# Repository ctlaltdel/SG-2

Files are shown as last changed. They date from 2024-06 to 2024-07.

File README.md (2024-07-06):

# SG-2 Synthesiser Guitar

## An experimental synth intended to be playable like a guitar

- 2 voices
- A softpot per voice for pitch selection
- A guitar string amplitude detector per voice for volume envelope
- Cartridge port for synth parameter selection

The synth is based around a Daisy Seed from Electrosmith, mounted in a custom PCB that provides the current sources and gating for the softpots, the string amplitude detectors for the voice envelopes, and the cartridge port interface. Power is provided via an internal USB powerbank, charged via a port mounted on the pickguard.

Current status: 
- Revision B of the main electronics board testing complete, awaiting permanent installation
- Port of Op6daisy FM synth engine by @carlvp up and running, including loading synth voice program from cartridge! 

Still to do:
- Add touch-sensitive pads to allow scale shifting up/down to mitigate the limitation of having only 2 strings
- Add a touch control to toggle \'stringless\' playing of the pitch softpots

Here\'s a video that hopefully gives some idea of what I'm aiming at: 

https://www.youtube.com/watch?v=BWaMOtsjMRc

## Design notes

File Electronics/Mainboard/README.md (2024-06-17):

### Credits

- The idea to use constant current to drive the softpots (which allows two-finger hammer-ons and pull-offs) instead of voltage  came from this article:

https://paia.com/dual-ribbon-howto/

- I was having trouble with sound artifacts on finger-off, which was solved with gating based heavily on user frijitz\'s posts on this thread:

https://electro-music.com/forum/topic-32246.html

- The preamp and peak detector of string envelope demodulation stages are based on the Sound Detector product from Sparkfun: 

https://www.sparkfun.com/products/12642

Original schematic by Bryan Jacquot may be found at:

https://cdn.sparkfun.com/assets/8/a/1/2/5/sound-detector-v11.pdf

Note the schematic for this product is released under the Creative Commons
Attribution Share-Alike 3.0 License: https://creativecommons.org/licenses/by-sa/3.0/

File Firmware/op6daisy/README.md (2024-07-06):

This is an adaption of the op6daisy firmware by carlvp: https://github.com/carlvp/daisylab/tree/main/op6daisy

The following modifications have been made:

* There is a single channel with 2 voices, 1 per pitch softpot
* The firmware is limited to a single voice program
* The MIDI dispatcher has been replaced by a routine that monitors the pitch gate signals and string envelope amplitudes
* The synth voice program is loaded from a cartridge (EEPROM connected via I2C), which is hot-swappable

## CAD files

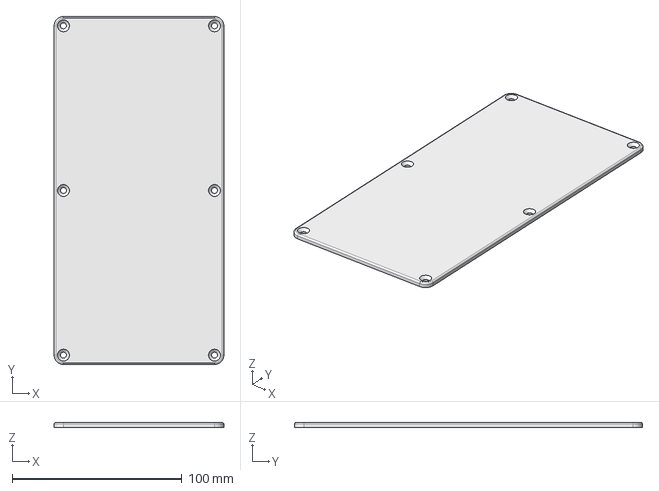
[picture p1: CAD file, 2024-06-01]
Mechanical/Backplate/backplate.FCStd
100.0 x 205.0 x 3.00 mm

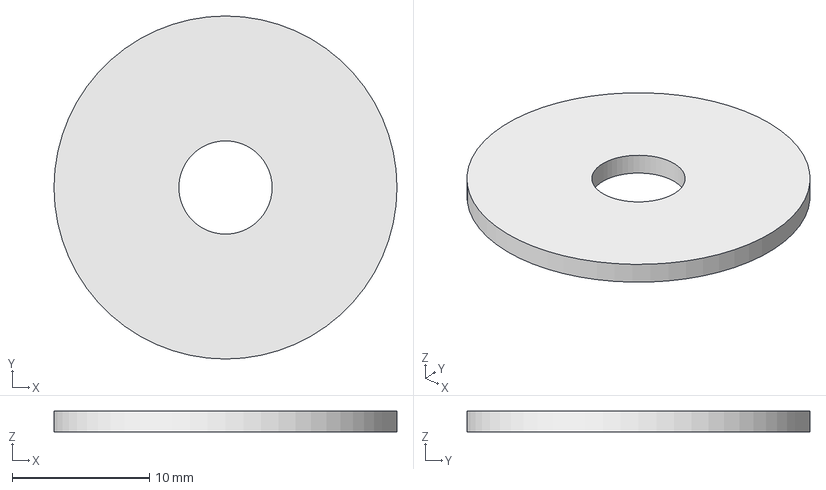
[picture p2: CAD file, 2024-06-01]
Mechanical/Misc/volume knob mount.FCStd
25.0 x 25.0 x 1.50 mm

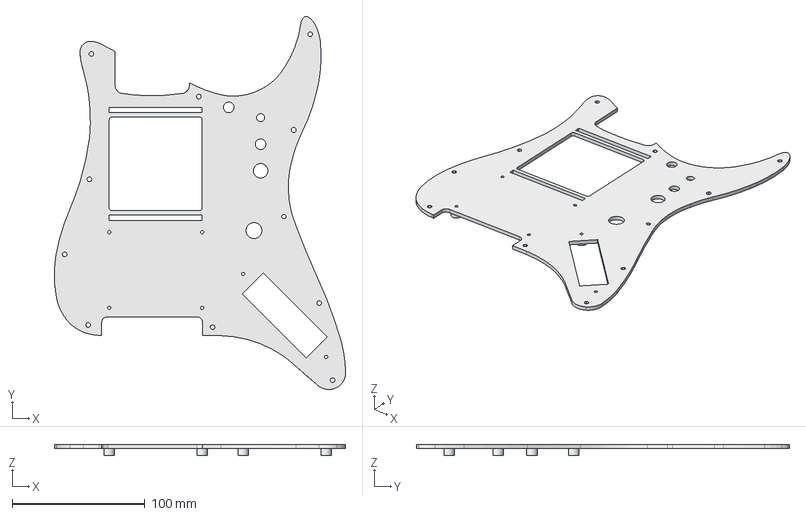
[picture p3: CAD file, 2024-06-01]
Mechanical/Pickguard/Pickguard.FCStd
219.3 x 280.9 x 8.00 mm

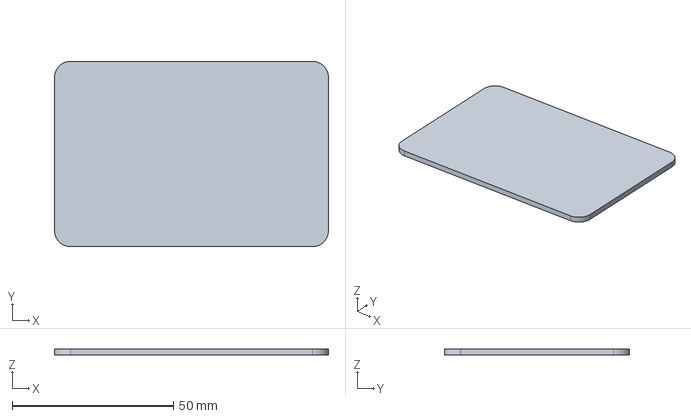
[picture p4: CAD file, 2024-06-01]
Mechanical/Misc/wiring cover.FCStd
85.0 x 57.5 x 2.00 mm

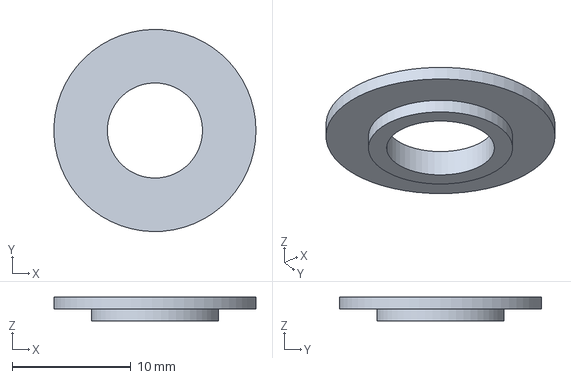
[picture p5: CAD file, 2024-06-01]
Mechanical/Misc/charging socket mount.FCStd
17.0 x 17.0 x 2.00 mm

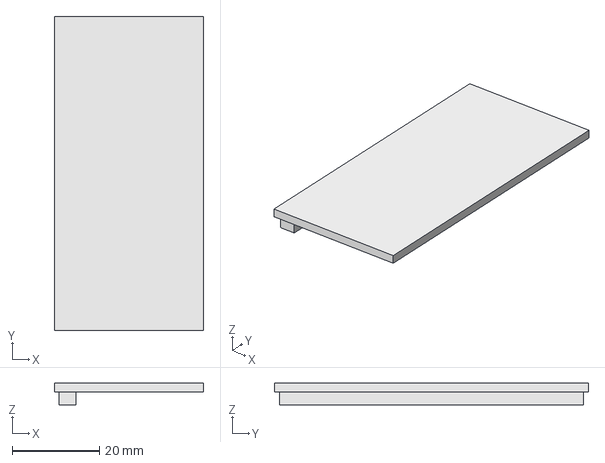
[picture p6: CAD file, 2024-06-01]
Mechanical/Misc/blanking plate.FCStd
34.2 x 72.0 x 5.00 mm

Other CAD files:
Mechanical/Backplate/backplate.stl
Mechanical/Pickguard/Pickguard.stl

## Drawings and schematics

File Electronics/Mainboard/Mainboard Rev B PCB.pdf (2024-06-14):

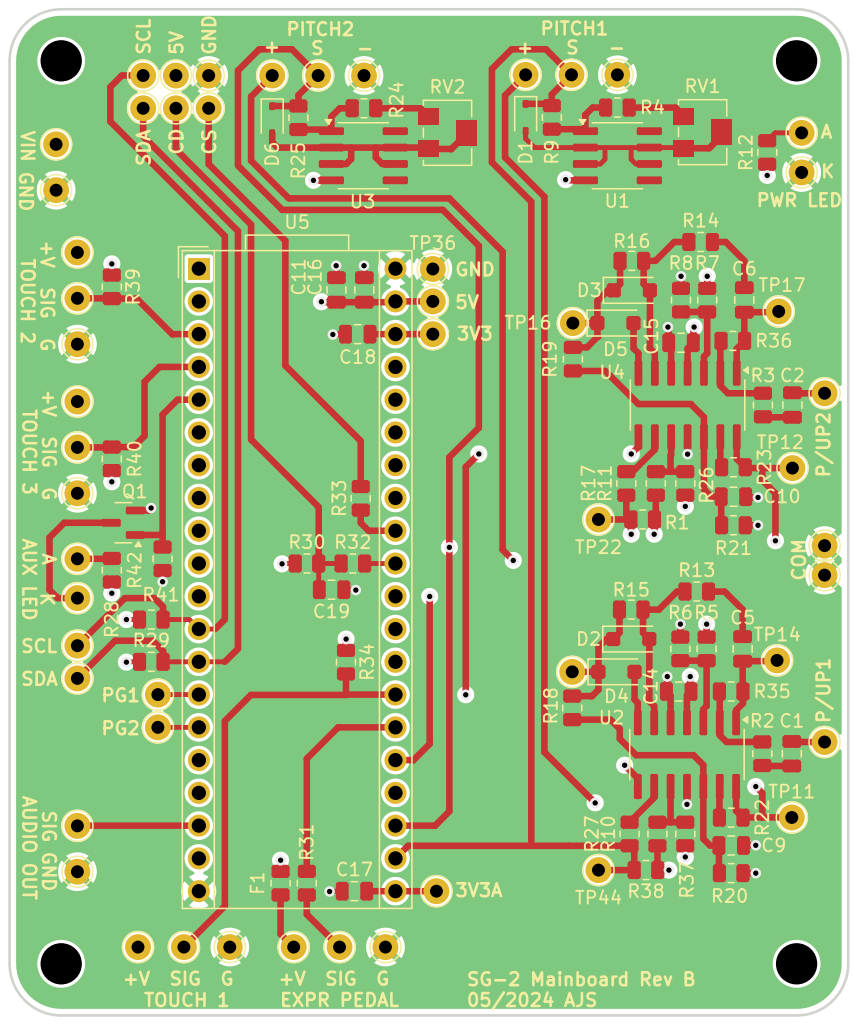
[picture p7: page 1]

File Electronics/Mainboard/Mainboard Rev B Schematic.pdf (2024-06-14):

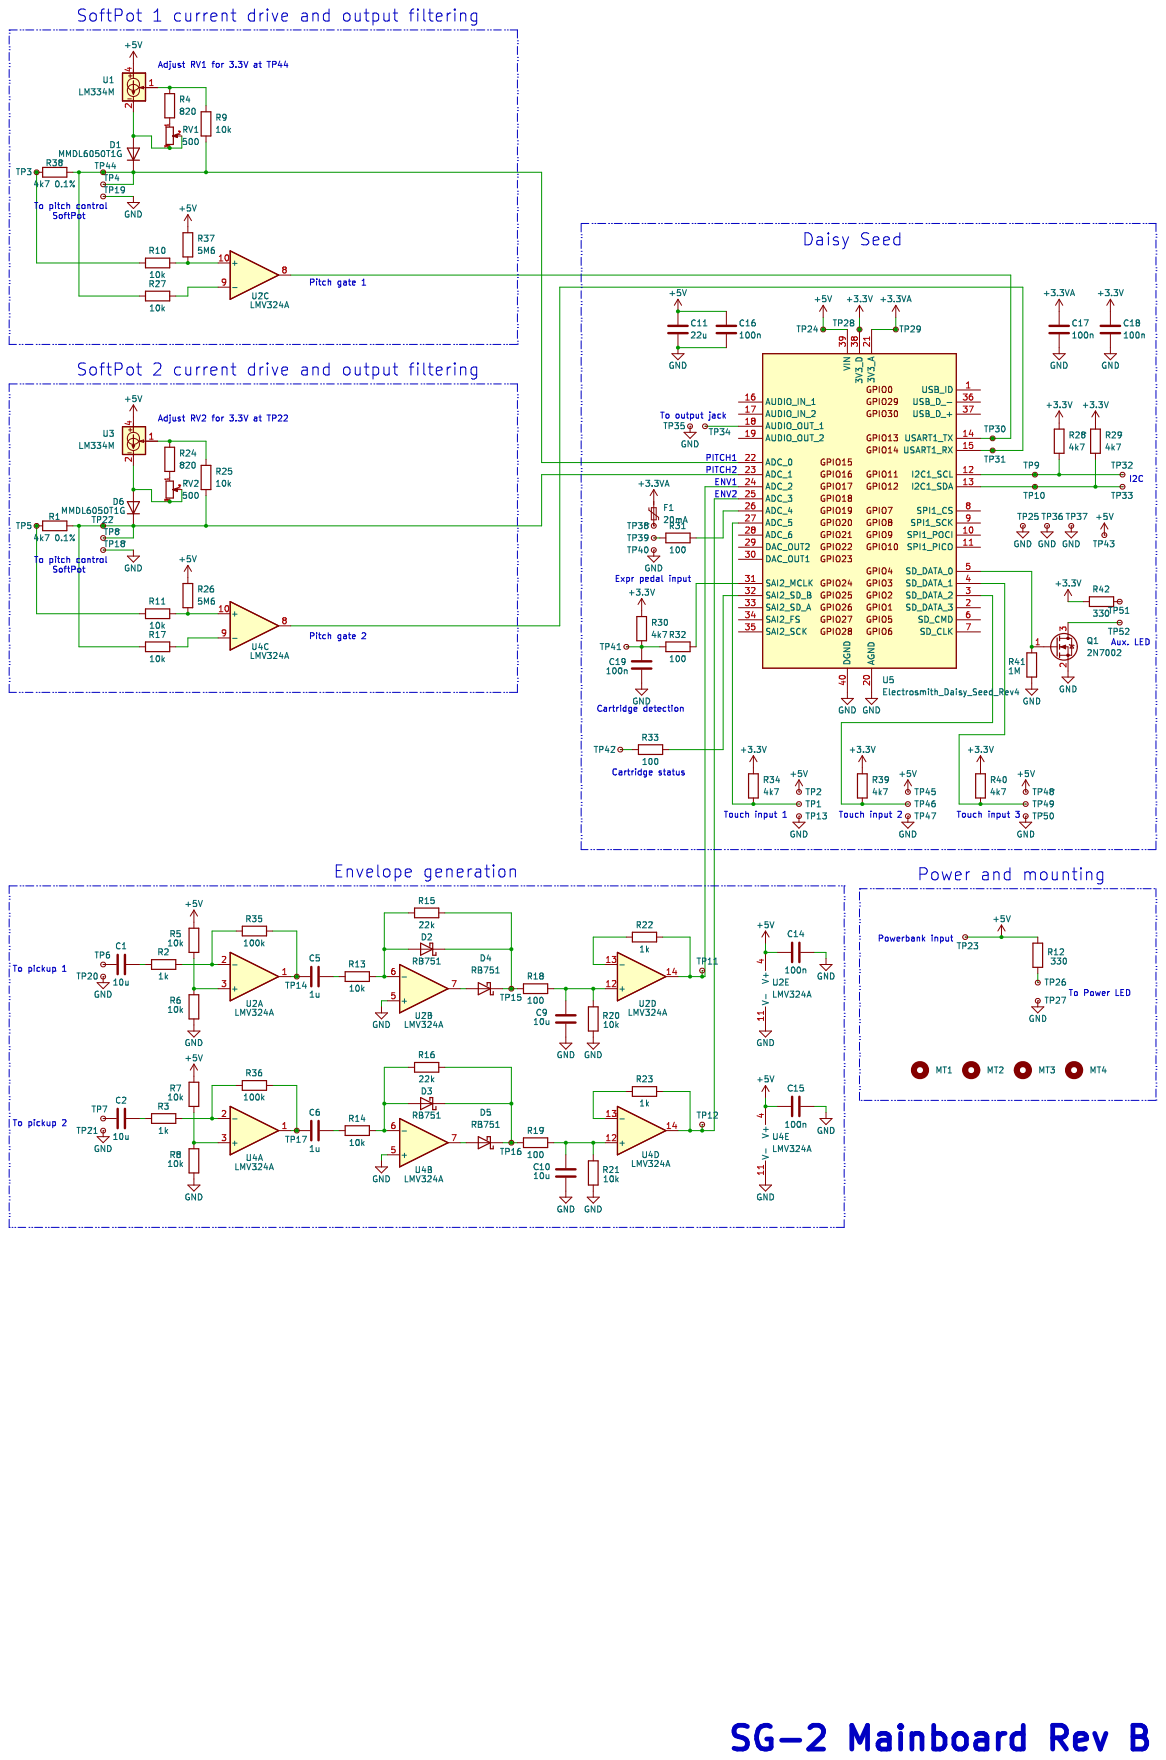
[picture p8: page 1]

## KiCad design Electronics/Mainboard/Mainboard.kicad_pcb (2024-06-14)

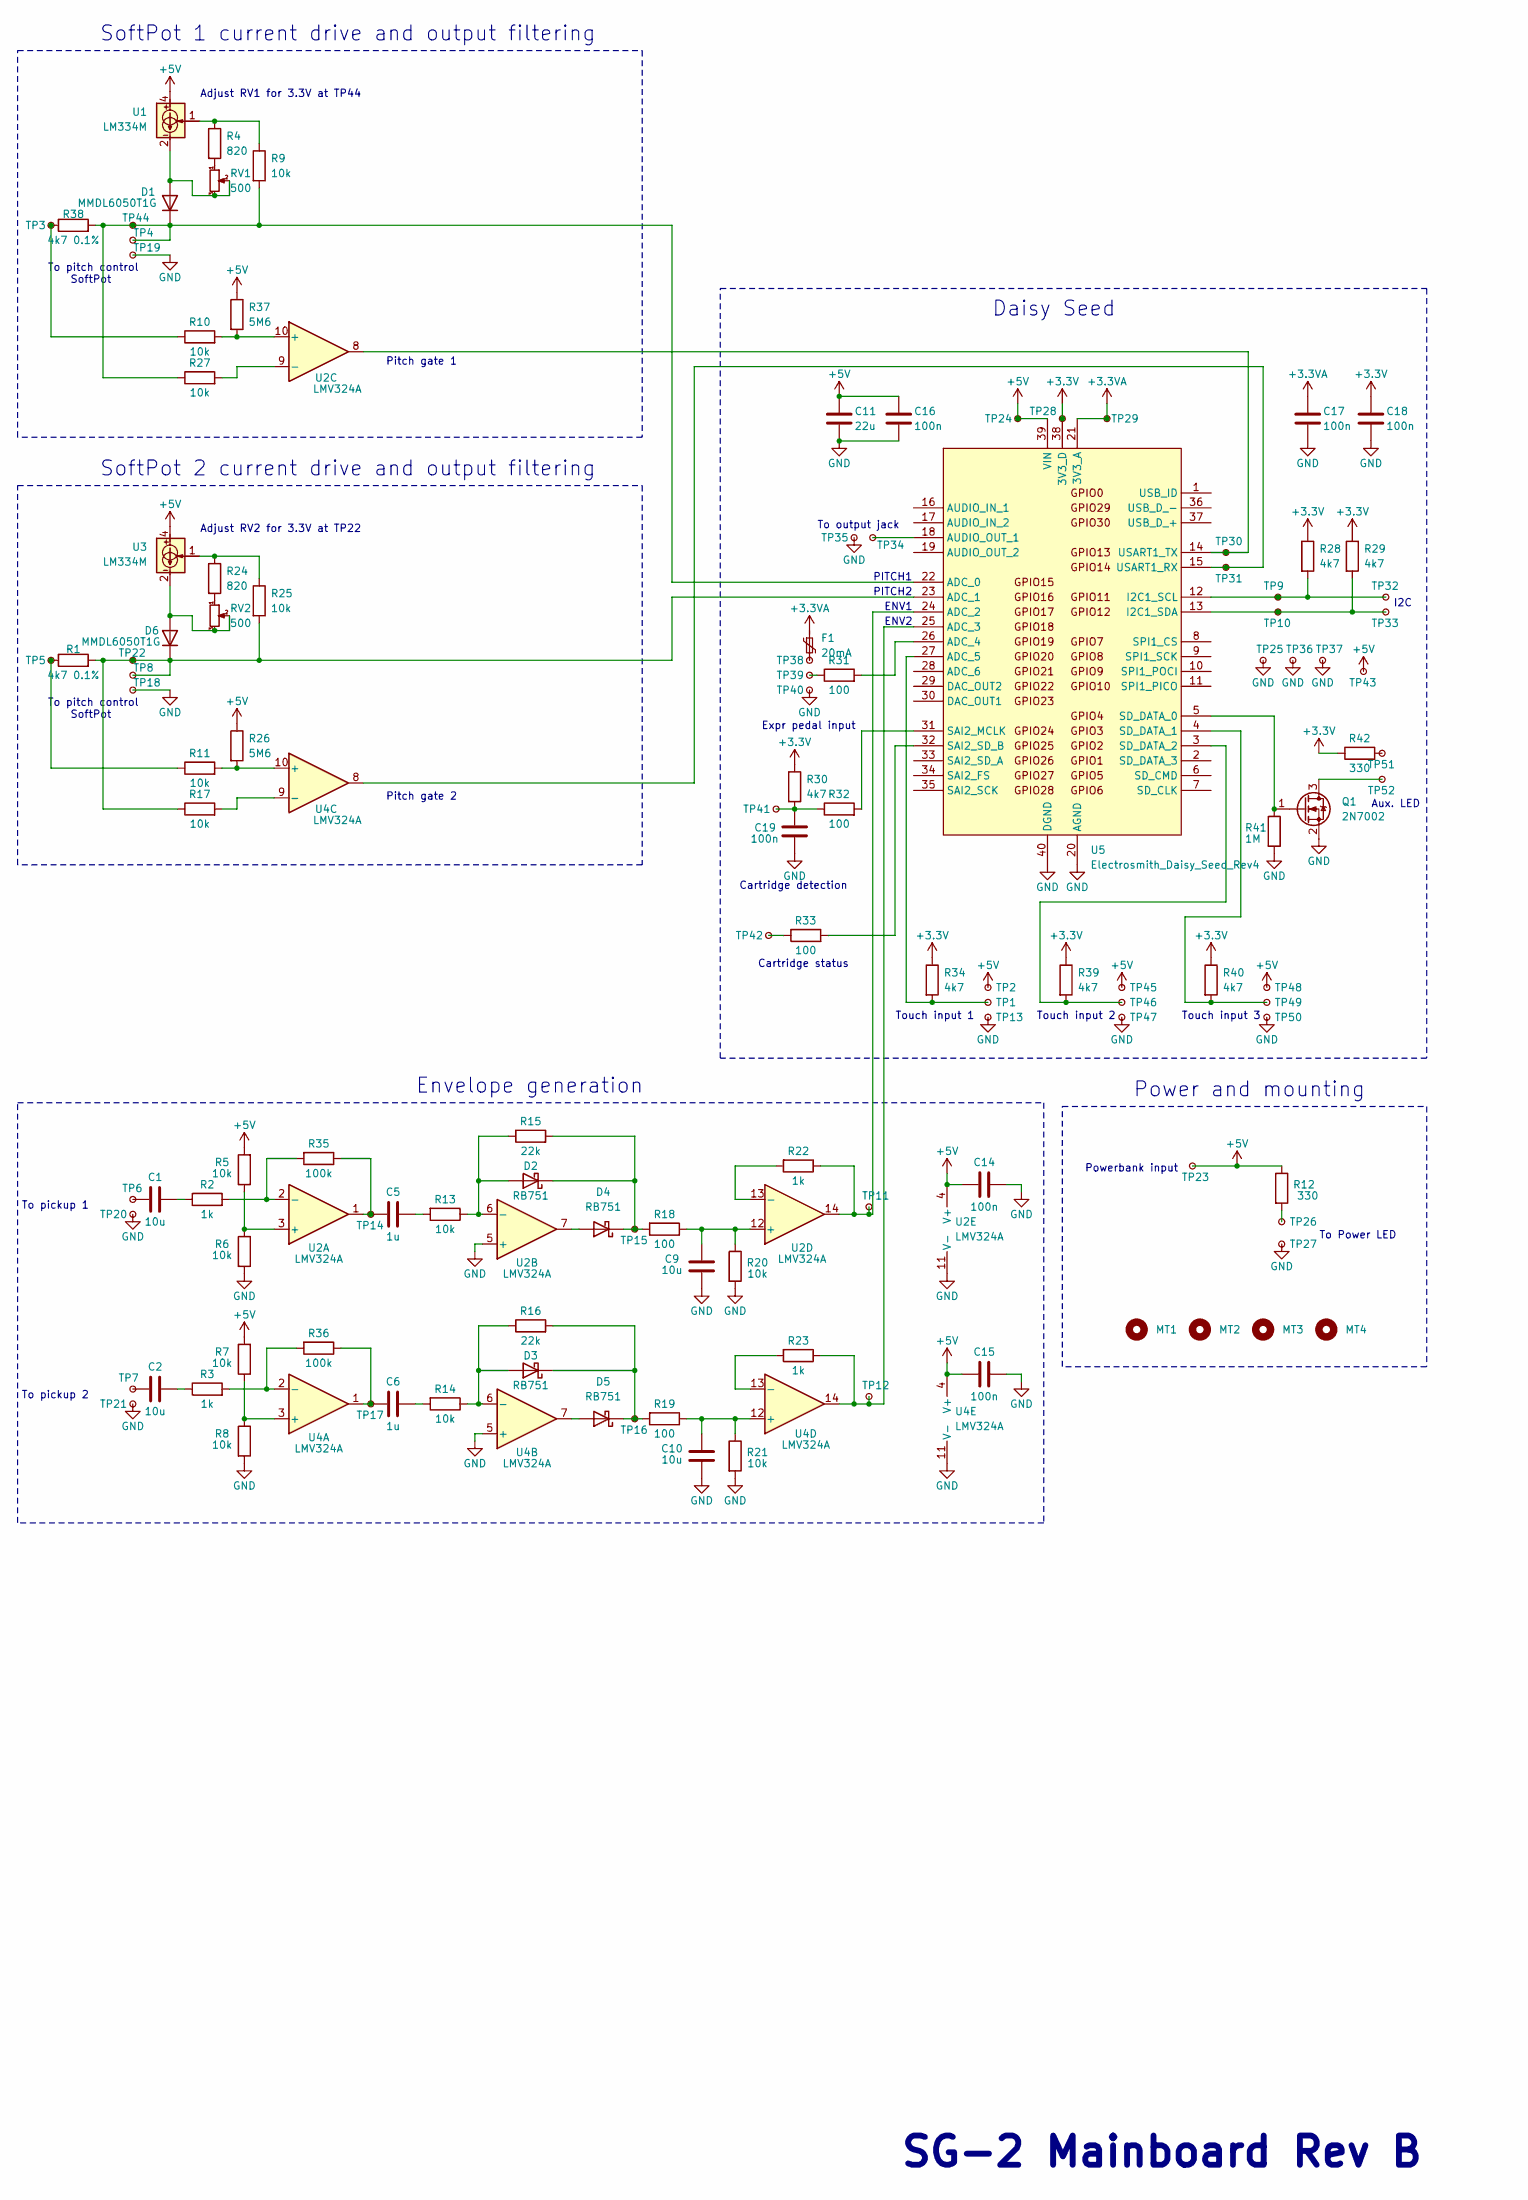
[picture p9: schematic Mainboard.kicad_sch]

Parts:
C1, C2, C9, C10: 10u; C_0805_2012Metric
C5, C6: 1u; C_0805_2012Metric
C11: 22u; C_0805_2012Metric
C14, C15, C16, C17, C18, C19: 100n; C_0805_2012Metric
D1, D6: MMDL6050T1G; D_SOD-323
D2, D3, D4, D5: RB751; D_SOD-123F
F1: 20mA; R_0805_2012Metric
MT1, MT2, MT3, MT4: MountingHole; MountingHole_3.2mm_M3
Q1: 2N7002; SOT-23
R1, R38: 4k7 0.1%; R_0805_2012Metric
R2, R3, R22, R23: 1k; R_0805_2012Metric
R4, R24: 820; R_0805_2012Metric
R5, R6, R7, R8, R9, R10, R11, R13, R14, R17, R20, R21, R25, R27: 10k; R_0805_2012Metric
R12, R42: 330; R_0805_2012Metric
R15, R16: 22k; R_0805_2012Metric
R18, R19, R31, R32, R33: 100; R_0805_2012Metric
R26, R37: 5M6; R_0805_2012Metric
R28, R29, R30, R34, R39, R40: 4k7; R_0805_2012Metric
R35, R36: 100k; R_0805_2012Metric
R41: 1M; R_0805_2012Metric
RV1, RV2: 500; Potentiometer_Bourns_3224W_Vertical
TP1, TP2, TP3, TP4, TP5, TP6, TP7, TP8, TP9, TP10, TP11, TP12, TP13, TP14, TP15, TP16, TP17, TP18, TP19, TP20, TP21, TP22, TP23, TP24, TP25, TP26, TP27, TP28, TP29, TP30, TP31, TP32, TP33, TP34, TP35, TP36, TP37, TP38, TP39, TP40, TP41, TP42, TP43, TP44, TP45, TP46, TP47, TP48, TP49, TP50, TP51, TP52: TestPoint_Small; TestPoint_THTPad_D2.0mm_Drill1.0mm
U1, U3: LM334M; SOIC-8_3.9x4.9mm_P1.27mm
U2, U4: LMV324A; SOIC-14_3.9x8.7mm_P1.27mm
U5: Electrosmith_Daisy_Seed_Rev4; Electrosmith_Daisy_Seed

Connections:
+3.3V: C18.2, R28.1, R29.1, R30.1, R34.1, R39.1, R40.1, R42.1, TP28.1, U5.38 (3V3_D)
+3.3VA: C17.2, F1.1, TP29.1, U5.21 (3V3_A)
+5V: C11.2, C14.2, C15.2, C16.2, R5.2, R7.2, R12.1, R26.1, R37.1, TP2.1, TP23.1, TP24.1, TP43.1, TP45.1, TP48.1, U1.4, U2.4 (V+), U3.4, U4.4 (V+), U5.39 (VIN)
GND: C9.2, C10.2, C11.1, C14.1, C15.1, C16.1, C17.1, C18.1, C19.1, Q1.2 (S), R6.2, R8.2, R20.2, R21.2, R41.2, TP13.1, TP18.1, TP19.1, TP20.1, TP21.1, TP25.1, TP27.1, TP35.1, TP36.1, TP37.1, TP40.1, TP47.1, TP50.1, U2.5 (+), U2.11 (V-), U4.5 (+), U4.11 (V-), U5.20 (AGND), U5.40 (DGND)
unnamed: C1.1, R2.1
unnamed: C1.2, TP6.1
unnamed: C2.1, R3.1
unnamed: C2.2, TP7.1
unnamed: C5.1, R13.2
unnamed: C5.2, R35.1, TP14.1, U2.1
unnamed: C6.1, R14.2
unnamed: C6.2, R36.1, TP17.1, U4.1
unnamed: C19.2, R30.2, R32.1, TP41.1
unnamed: D1.2 (A), RV1.2, RV1.3, U1.2, U1.3, U1.6, U1.7
unnamed: D1.1 (K), R9.2, R27.1, R38.2, TP4.1, TP44.1, U5.22 (ADC_0)
unnamed: D2.2 (A), R13.1, R15.1, U2.6 (-)
unnamed: D2.1 (K), D4.1 (K), R15.2, R18.2, TP15.1
unnamed: D3.2 (A), R14.1, R16.1, U4.6 (-)
unnamed: D3.1 (K), D5.1 (K), R16.2, R19.2, TP16.1
unnamed: D4.2 (A), U2.7
unnamed: D5.2 (A), U4.7
unnamed: D6.2 (A), RV2.2, RV2.3, U3.2, U3.3, U3.6, U3.7
unnamed: D6.1 (K), R1.2, R17.1, R25.2, TP8.1, TP22.1, U5.23 (ADC_1)
unnamed: F1.2, TP38.1
unnamed: Q1.3 (D), TP52.1
unnamed: Q1.1 (G), R41.1, U5.5 (SD_DATA_0)
unnamed: R1.1, R11.1, TP5.1
unnamed: R4.1, R9.1, U1.1
unnamed: R4.2, RV1.1
unnamed: R10.1, R38.1, TP3.1
unnamed: R12.2, TP26.1
unnamed: R24.1, R25.1, U3.1
unnamed: R24.2, RV2.1
unnamed: R31.1, TP39.1
unnamed: R33.1, TP42.1
unnamed: R42.2, TP51.1
unnamed: R5.1, R6.1, U2.3 (+)
unnamed: R2.2, R35.2, U2.2 (-)
unnamed: R10.2, R37.2, U2.10 (+)
unnamed: R27.2, U2.9 (-)
unnamed: C9.1, R18.1, R20.1, U2.12 (+)
unnamed: R22.2, U2.13 (-)
unnamed: R7.1, R8.1, U4.3 (+)
unnamed: R3.2, R36.2, U4.2 (-)
unnamed: R11.2, R26.2, U4.10 (+)
unnamed: R17.2, U4.9 (-)
unnamed: C10.1, R19.1, R21.1, U4.12 (+)
unnamed: R23.2, U4.13 (-)
unnamed: R22.1, TP11.1, U2.14, U5.24 (ADC_2)
unnamed: R23.1, TP12.1, U4.14, U5.25 (ADC_3)
unnamed: R31.2, U5.26 (ADC_4)
unnamed: R34.2, TP1.1, U5.27 (ADC_5)
unnamed: TP34.1, U5.18 (AUDIO_OUT_1)
unnamed: R28.2, TP9.1, TP32.1, U5.12 (I2C1_SCL)
unnamed: R29.2, TP10.1, TP33.1, U5.13 (I2C1_SDA)
unnamed: R32.2, U5.31 (SAI2_MCLK)
unnamed: R33.2, U5.32 (SAI2_SD_B)
unnamed: R40.2, TP49.1, U5.4 (SD_DATA_1)
unnamed: R39.2, TP46.1, U5.3 (SD_DATA_2)
unnamed: TP31.1, U4.8, U5.15 (USART1_RX)
unnamed: TP30.1, U2.8, U5.14 (USART1_TX)

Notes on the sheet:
To Power LED
To output jack
Power and mounting
Cartridge status
Powerbank input
Cartridge detection
Pitch gate 1
Envelope generation
SoftPot 2 current drive and output filtering
Touch input 1
ENV2
Aux. LED
Adjust RV1 for 3.3V at TP44
To pitch control SoftPot
I2C
SoftPot 1 current drive and output filtering
Pitch gate 2
PITCH1
Touch input 2
Expr pedal input
To pickup 2
Daisy Seed
To pickup 1
PITCH2
SG-2 Mainboard Rev B
Adjust RV2 for 3.3V at TP22
Touch input 3
ENV1

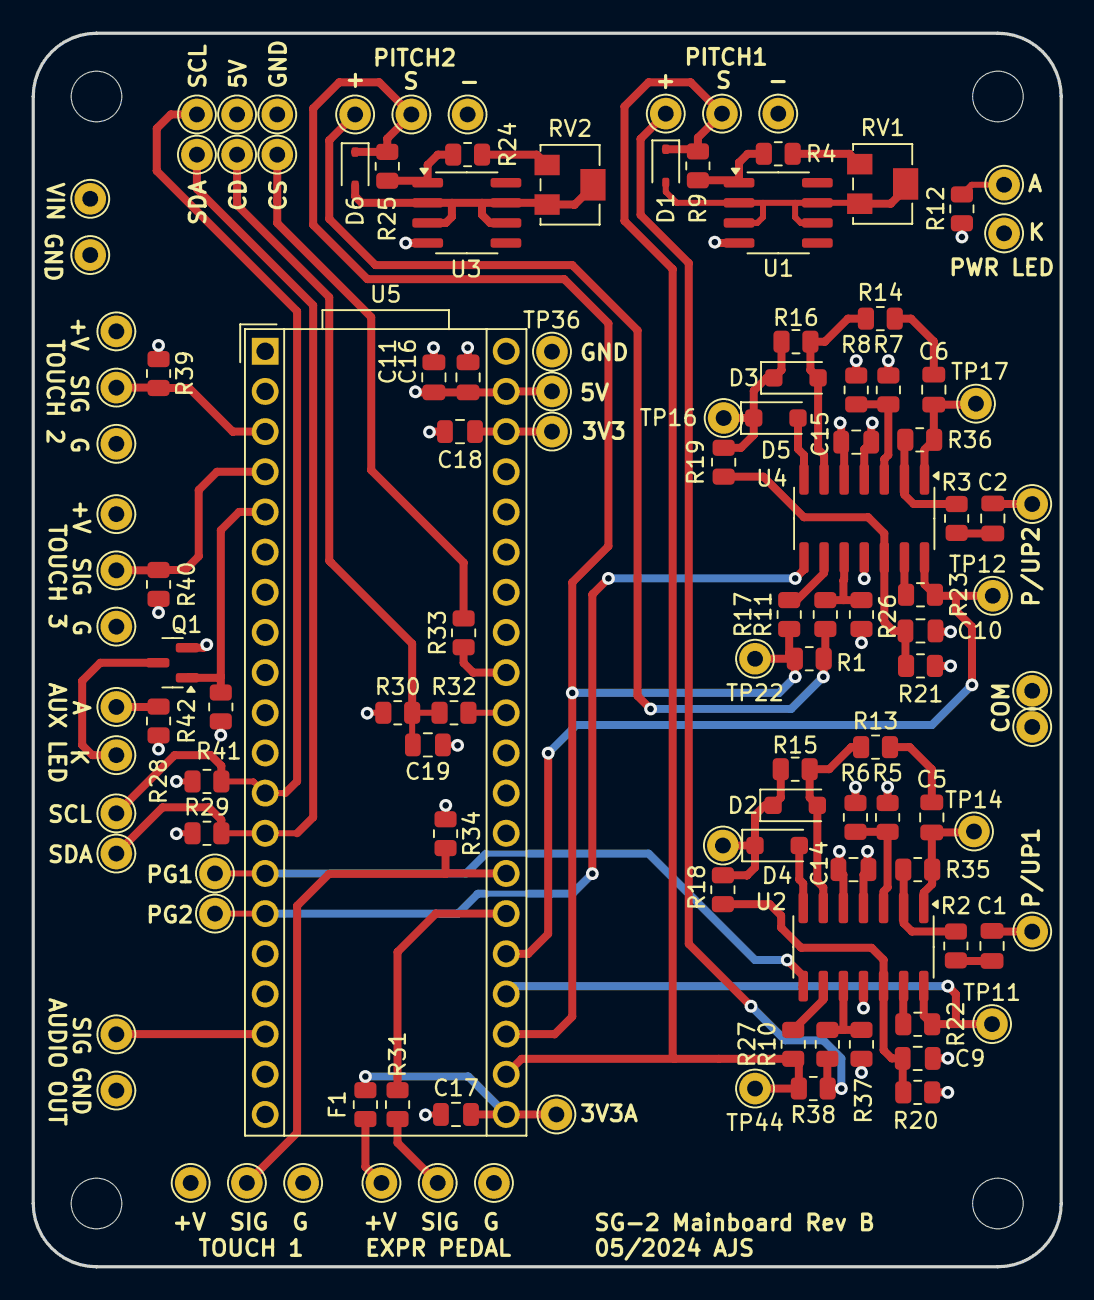
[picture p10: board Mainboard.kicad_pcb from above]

Board: 4 copper layers, 65.0 x 78.0 mm, 126 parts (0 on the bottom side), 61 nets.

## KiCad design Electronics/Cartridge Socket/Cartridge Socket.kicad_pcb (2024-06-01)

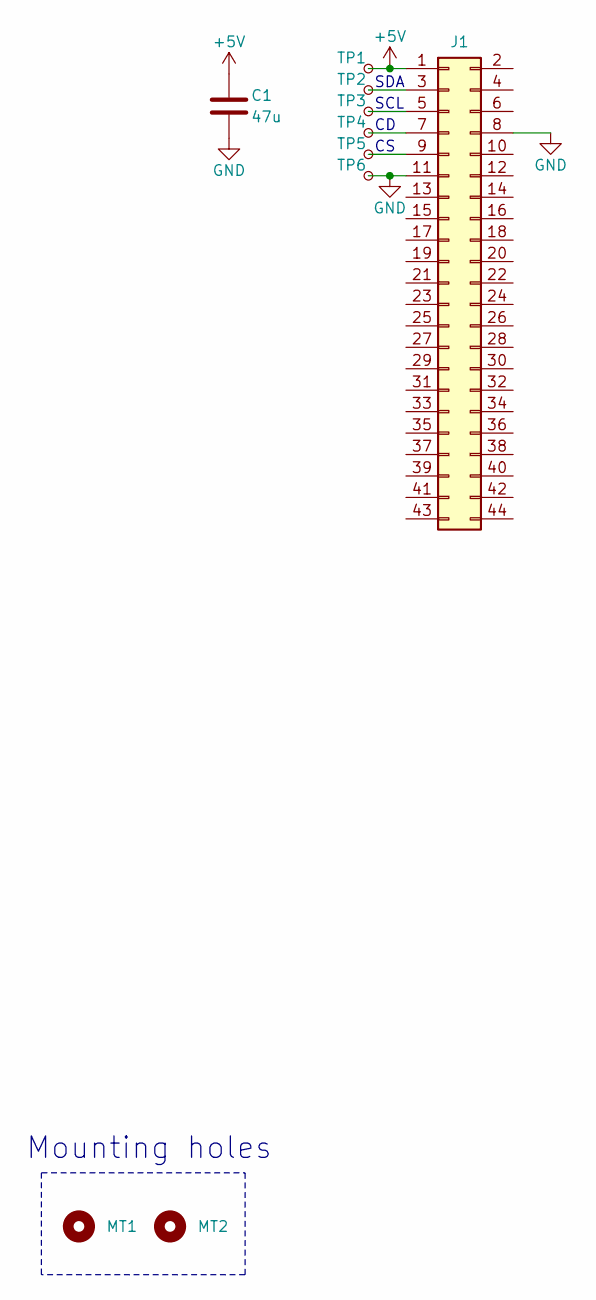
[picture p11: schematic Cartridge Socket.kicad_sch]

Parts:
C1: 47u; C_0805_2012Metric
J1: Conn_02x22_Odd_Even; TE_5530843-4
MT1, MT2: MountingHole; MountingHole_3.2mm_M3
TP1, TP2, TP3, TP4, TP5, TP6: TestPoint_Small; TestPoint_THTPad_D1.5mm_Drill0.7mm

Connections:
+5V: C1.2, J1.1, TP1.1
GND: C1.1, J1.8, J1.11, TP6.1
unnamed: J1.3, TP2.1
unnamed: J1.5, TP3.1
unnamed: J1.7, TP4.1
unnamed: J1.9, TP5.1

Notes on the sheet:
SCL
Mounting holes
SDA

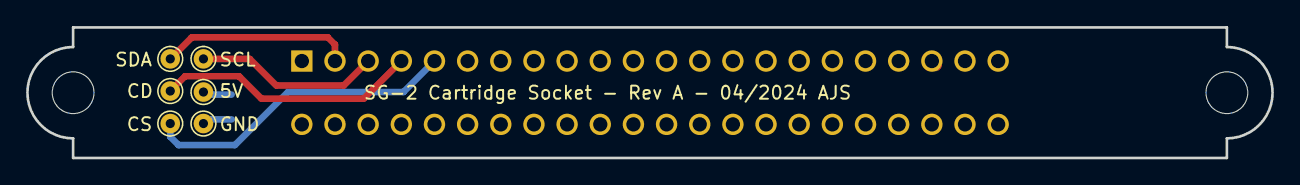
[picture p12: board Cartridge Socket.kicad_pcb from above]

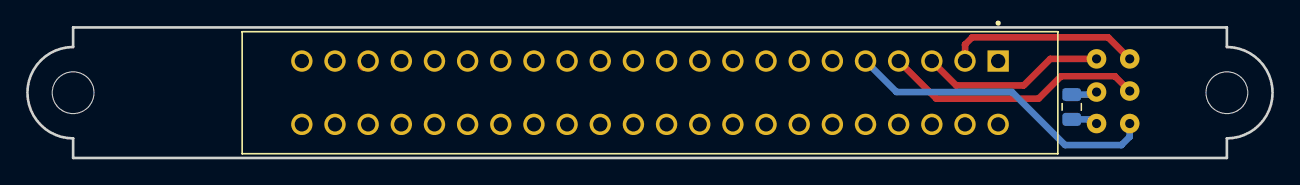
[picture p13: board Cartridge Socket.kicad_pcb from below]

Board: 4 copper layers, 95.4 x 10.0 mm, 10 parts (2 on the bottom side), 6 nets.

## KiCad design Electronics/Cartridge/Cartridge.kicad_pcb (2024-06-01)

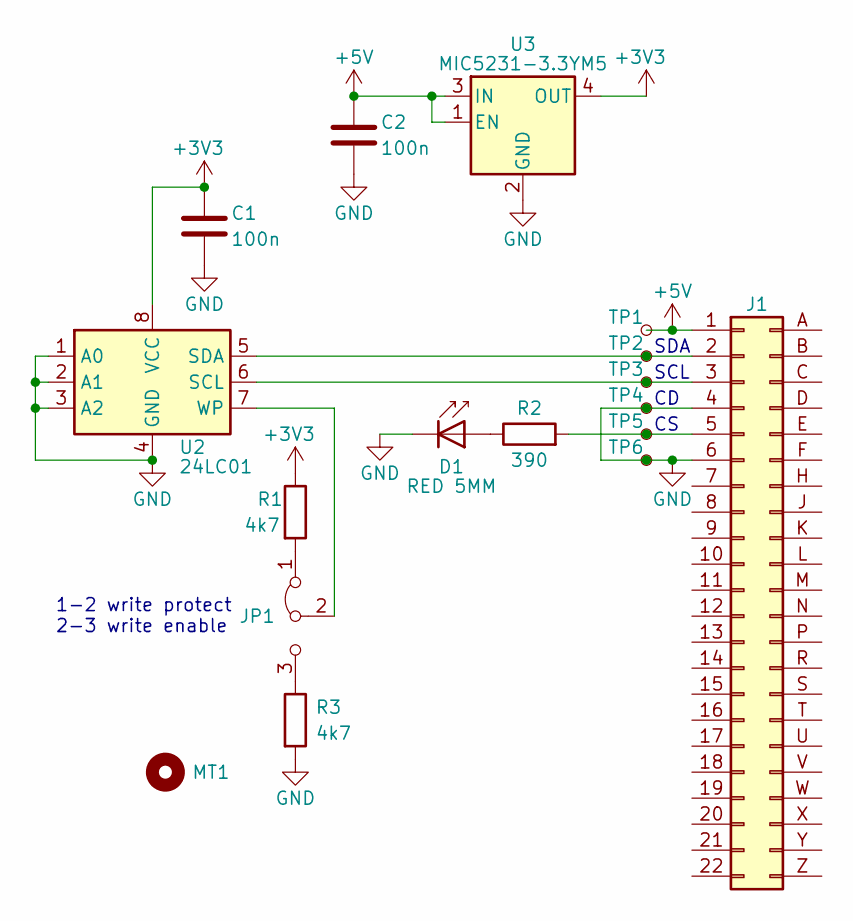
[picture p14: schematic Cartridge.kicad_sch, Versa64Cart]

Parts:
C1, C2: 100n; C_0603_1608Metric
D1: RED 5MM; LED_D5.0mm_IRGrey
J1: Conn_02x22_Odd_Even; C64_EXPANSION_PORT
JP1: Jumper_3_Bridged12; PinHeader_1x03_P2.54mm_Horizontal
MT1: MountingHole; MountingHole_5mm
R1, R3: 4k7; R_0805_2012Metric
R2: 390; R_0805_2012Metric
TP1, TP2, TP3, TP4, TP5, TP6: TestPoint_Small; TestPoint_THTPad_D1.5mm_Drill0.7mm
U2: 24LC01; SOIC-8_3.9x4.9mm_P1.27mm
U3: MIC5231-3.3YM5; SOT-23-5

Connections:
+3V3: C1.2, R1.1, U2.8 (VCC), U3.4 (OUT)
+5V: C2.2, J1.1, TP1.1, U3.1 (EN), U3.3 (IN)
GND: C1.1, C2.1, D1.1 (K), J1.4, J1.6, R3.2, TP4.1, TP6.1, U2.1 (A0), U2.2 (A1), U2.3 (A2), U2.4 (GND), U3.2 (GND)
unnamed: D1.2 (A), R2.1
unnamed: J1.5, R2.2, TP5.1
unnamed: JP1.1 (A), R1.2
unnamed: JP1.3 (B), R3.1
unnamed: JP1.2 (C), U2.7 (WP)
unnamed: J1.3, TP3.1, U2.6 (SCL)
unnamed: J1.2, TP2.1, U2.5 (SDA)

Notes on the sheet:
SDA
SCL
1-2 write protect 2-3 write enable

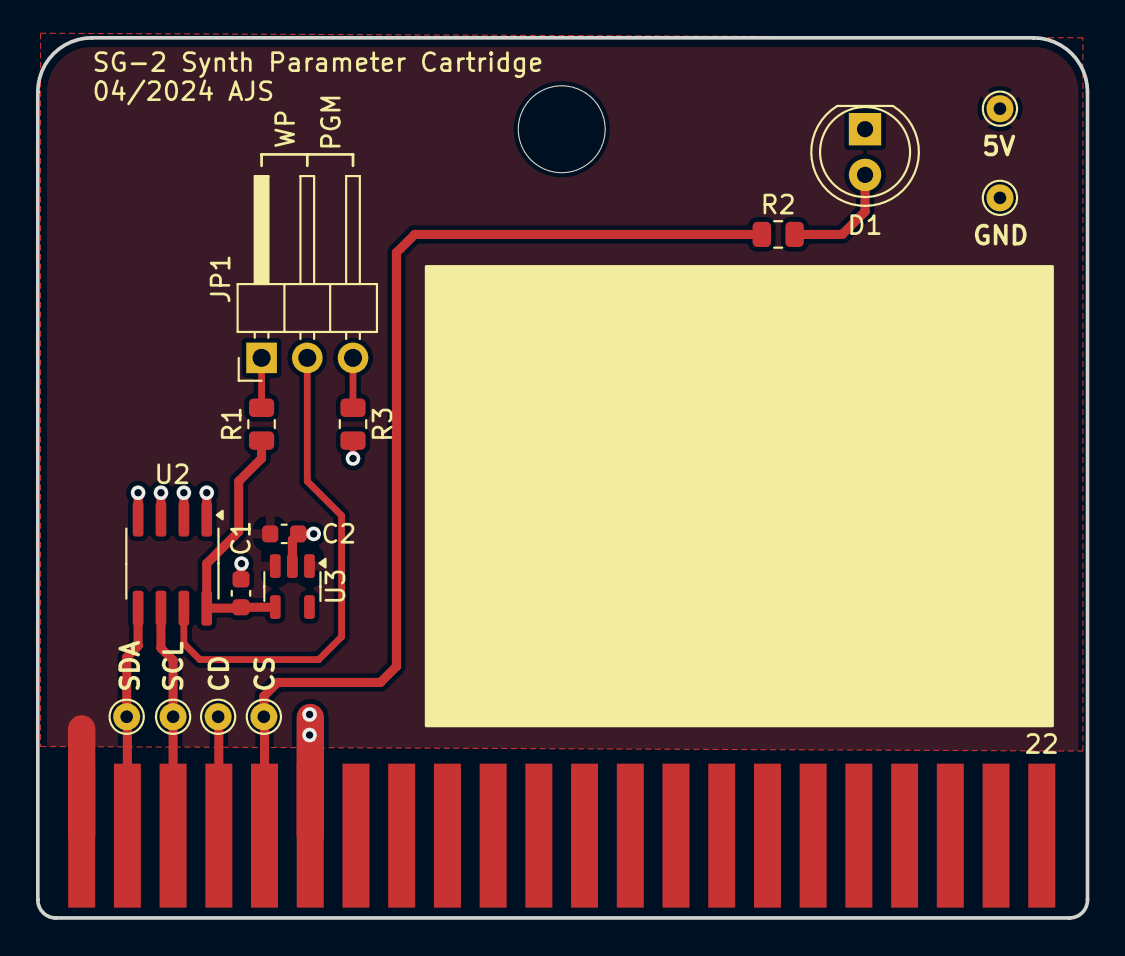
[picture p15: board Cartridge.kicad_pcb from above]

Board: 2 copper layers, 58.3 x 48.9 mm, 17 parts (0 on the bottom side), 10 nets.

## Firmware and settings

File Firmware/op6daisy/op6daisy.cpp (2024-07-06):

#include "configuration.h"
#include "hardware.h"
#include "AudioPath.h"
#include "Instrument.h"
#include "SG2Dispatcher.h"
#include "Cartridge.h"
#include "Program.h"

#include <daisy_seed.h>
static daisy::DaisySeed DaisyHw;
#define DaisySeedHw DaisyHw

Instrument theOp6Daisy;
SG2Dispatcher theSG2Dispatcher;
CartridgeMonitor theCartridgeMonitor;
CartStatusLED cart_led;

void startAudioCallback(daisy::AudioHandle::AudioCallback callback,
			unsigned blockSize) {
  DaisySeedHw.audio_handle.SetBlockSize(blockSize);
  DaisyHw.StartAudio(callback);
}

int main(void)
{
  // Init
  DaisyHw.Init();

  daisy::AdcChannelConfig adc_cfg[4];
  adc_cfg[0].InitSingle(daisy::seed::A0);
  adc_cfg[1].InitSingle(daisy::seed::A1);
  adc_cfg[2].InitSingle(daisy::seed::A2);
  adc_cfg[3].InitSingle(daisy::seed::A3);
	DaisyHw.adc.Init(adc_cfg, 4);
  DaisyHw.adc.Start();

  theOp6Daisy.Init();
  theCartridgeMonitor.Init(&theOp6Daisy, &cart_led);
  theSG2Dispatcher.Init(&theOp6Daisy, &DaisyHw);

  // Main loop
  DaisySeedHw.SetLed(false); // LED signals gate + buffer underrun
  startAudioPath();
  while(1) {
    theCartridgeMonitor.Process();
    processAudioPath(&theOp6Daisy);
    theSG2Dispatcher.Process();
  }
}

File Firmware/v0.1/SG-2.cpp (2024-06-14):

#include "daisy_seed.h"
#include "daisysp.h"
#include "SG-2.h"
#include <cmath>

using namespace daisy;
using namespace daisysp;

static DaisySeed hw;
Chorus chorus;
static MoogLadder flt1, flt2;
static VariableSawOscillator voice1, voice2;
ReverbSc verb;
Configuration config =
{
	{56, 61}	
};
float string_base_freq[2];
bool env_hyst_flag[2];
GPIO pitch_gate[2]; 

float flt1_cutoff, flt2_cutoff;

void AudioCallback(AudioHandle::InputBuffer in, AudioHandle::OutputBuffer out, size_t size)
{
	float sig1=0.f, sig2=0.f, string_env_1, string_env_2, pitch_1, pitch_2;

	for (size_t i = 0; i < size; i++)
	{
		pitch_1 = GetPitch(PITCH_1);
		if(pitch_1 != 0.f)
		{
			string_env_1 = GetEnv(ENV_1); 
		    voice1.SetFreq(pitch_1);
			flt1_cutoff = pitch_1 * FLT_TRACK_SLOPE + FLT_TRACK_OFFSET;
			sig1 = voice1.Process() * string_env_1;
			flt1.SetFreq(flt1_cutoff);
			sig1 = flt1.Process(sig1);
		}

		pitch_2 = GetPitch(PITCH_2);
		if(pitch_2 != 0.f)
		{
			string_env_2 = GetEnv(ENV_2); 
		    voice2.SetFreq(pitch_2);
			flt2_cutoff = pitch_2 * FLT_TRACK_SLOPE + FLT_TRACK_OFFSET;
			sig2 = voice2.Process() * string_env_2;
			flt2.SetFreq(flt2_cutoff);
			sig2 = flt2.Process(sig2);
		}

		float sig = chorus.Process(sig1+sig2);
//		out[0][i] = out[1][i] = sig;
		verb.Process(sig, sig, &out[0][i], &out[1][i]);
	}
}

int main(void)
{ 
	env_hyst_flag[0] = env_hyst_flag[1] = false;

	string_base_freq[0] = mtof((float)config.string_base_midi[0]);
	string_base_freq[1] = mtof((float)config.string_base_midi[1]);

	hw.Init();
	hw.SetAudioBlockSize(4); // number of samples handled per callback
	hw.SetAudioSampleRate(SaiHandle::Config::SampleRate::SAI_48KHZ);
	float samplerate = hw.AudioSampleRate();

	pitch_gate[0].Init(seed::D13, GPIO::Mode::INPUT, GPIO::Pull::NOPULL);
	pitch_gate[1].Init(seed::D14, GPIO::Mode::INPUT, GPIO::Pull::NOPULL);

    AdcChannelConfig adc_cfg[4];
    adc_cfg[0].InitSingle(seed::A0);
    adc_cfg[1].InitSingle(seed::A1);
    adc_cfg[2].InitSingle(seed::A2);
    adc_cfg[3].InitSingle(seed::A3);
	hw.adc.Init(adc_cfg, 4);
    hw.adc.Start();

    chorus.Init(samplerate);
    chorus.SetLfoFreq(.33f);
    chorus.SetLfoDepth(1.f);
    chorus.SetDelay(0.9f);
	chorus.SetFeedback(0.3);

    flt1.Init(samplerate);
    flt1.SetRes(0.9);
    flt2.Init(samplerate);
    flt2.SetRes(0.9);
	
    verb.Init(samplerate);
    verb.SetFeedback(0.9f);
    verb.SetLpFreq(2000.0f);

	voice1.Init(samplerate);
	voice2.Init(samplerate);
	voice1.SetWaveshape(0.5f);
	voice2.SetWaveshape(0.5f);
 
	hw.StartAudio(AudioCallback);
	while(1) {}
}

float GetPitch(int channel)
{
	float pos, pitch;

	pitch = 0.f;
	if(pitch_gate[channel].Read())
	{
		pos = hw.adc.GetFloat(channel);
		pitch = string_base_freq[channel] * ((B3 * pow(pos, 3)) + (B2 * pow(pos, 2)) + (B1 * pos) + B0);
	}
	return pitch;
}

float GetEnv(int channel)
{
	float env;

	env = hw.adc.GetFloat(channel); 
	if(env_hyst_flag[channel-2])
	{
		if(env >= ENV_THR_2)
		{
			env_hyst_flag[channel-2] = false;
		}
		else env = 0.f;
	}
	else
	{
		if(env <= ENV_THR_1)
		{
			env_hyst_flag[channel-2] = true;
			env = 0.f;
		}
	}
	
	return env;
}

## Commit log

2024-06-14 Rev B Mainboard and demo firmware
    [Mainboard.kicad_pcb, Mainboard.kicad_sch]
2024-07-06 Op6daisy port initial commit
    [configuration.h]
